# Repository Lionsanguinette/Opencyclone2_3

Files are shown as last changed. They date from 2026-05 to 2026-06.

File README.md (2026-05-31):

# Opencyclone2_3
This repository contains the complete documentation and production files for Opencyclone_2.3, an open-source vacuum cleaner developed by Lion Sanguinette and originally initiated together with Jonathan Stein during their Industrial Design studies at Burg Giebichenstein University of Art and Design.

The folders include all files required to understand, reproduce, modify, and further develop the project. These comprise 3D-printable STL files, editable CAD data in STEP format, technical components, preparation files, assembly instructions, and part lists. The documentation is structured to support both individual makers and professional manufacturers.

Opencyclone_2.3 explores how an everyday industrial product can be redesigned as an open, repairable, and adaptable system. By making all relevant design and production information publicly accessible, the project encourages local manufacturing, repair, and collaborative development while demonstrating that open-source hardware can achieve the functionality and quality expected from contemporary consumer products.

The repository is intended not only as a source of manufacturing data, but also as a resource for learning, experimentation, and further contributions to the project.

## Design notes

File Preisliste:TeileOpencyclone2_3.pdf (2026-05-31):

## OPENCYCLONE_2.0 Preisliste

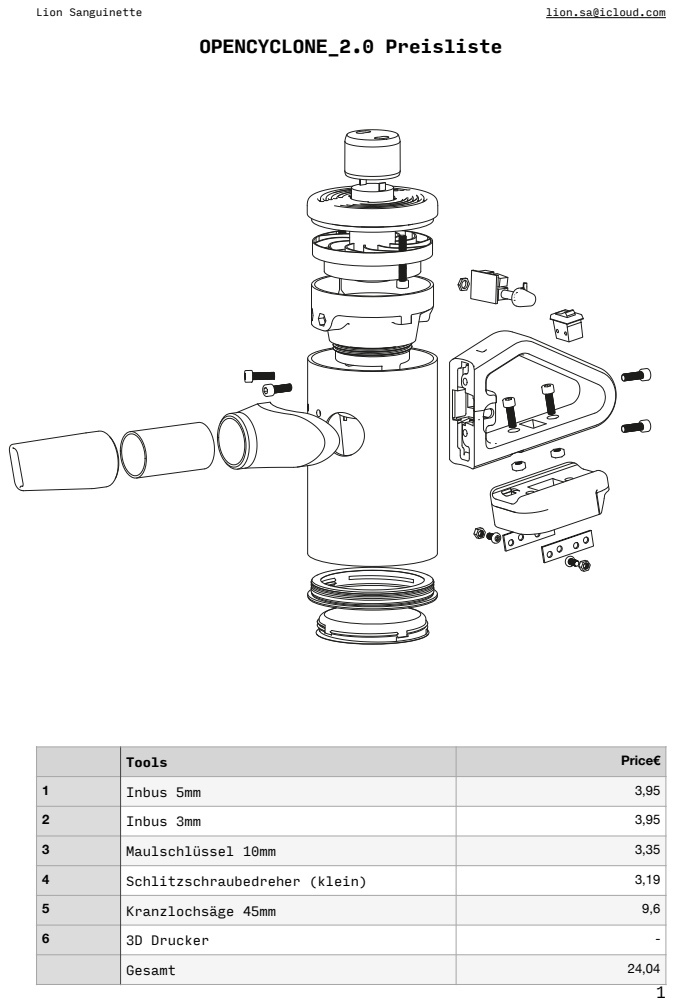
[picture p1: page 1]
Lion Sanguinette; lion.sa@icloud.com

Tools | Price€

1 | Inbus 5mm | 3,95
2 | Inbus 3mm | 3,95
3 | Maulschlüssel 10mm | 3,35
4 | Schlitzschraubedreher (klein) | 3,19
5 | Kranzlochsäge 45mm | 9,6
6 | 3D Drucker | -

Gesamt | 24,04

| Parts | Order € | Maß/ Gewicht/ Anzahl | Preis pro Staubi €
| Elektronik
1 | Kabel (Litze) 2,5 mm^2 | 5,51 | 2x 24cm/ 10cm/ 12cm/ 7cm | 0,67
2 Ringkabelschuhe M5 | 0,5-1,5mm^2 | 1,06 | 2 | 1,06
3 Flachsteckhülsen | 4,75mm/ 0,5 - 1,5mm^2 | 0,14 | 2 | 0,14
4 | Drehzahlregler | 6,59 | 1 | 3,30
5 | Makita Motor | 18,86 | 1 | 18,86
6 | Kippschalter | 4,69 | 1 | 4,69
| | 36,85 | | 28,72
| Zubehör
7 | AEG Staubsaugerfilter | 9,99 | 1 | 2,50
8 PVC Rohr HT Rohr DN 110 | 1000mm | 5,75 | 1 | 1,15
9 | PVC Rohr HT Rohr DN 40 | 1,75 | 1 | 0,15
10 | Filament | 19,99 | 370 gramm | 7,4
| | 37,48 | | 11,2
| Schrauben
11 M6 20mm DIN 912 | Zylinderkopfschraube | 4,7 | 6 | 2,79
12 M6 40mm DIN 912 | Zylinderkopfschraube | 7,7 | 2 | 0,16
13 M6 DIN934 | Sechskantmutter (Standard) | 3,2 | 6 | 0,19
14 50x14x1,5mm | Flachverbinder | 0,7 | 2 | 0,7
15 M5 10mm ISO 7380-1 | Halbrundkopfschrauben | 8,15 | 2 | 0,17
16 M5 DIN934 | Sechskantmutter (Standard) | 2,85 | 2 | 0,06
| | 27,3 | | 4,07
| Gesamt (ohne Werkzeug und ohne Akku/ Akku Ladegerät) | 101,63 | | 43,99

Elektronik

### 1. Kabel 1mm^2 14/24/34mm

https://www.amazon.de/FLRY-Fahrzeugleitung-Kabel-Litze-Stromkabel/dp/B084HJWB2L/ref=sr_1_2?
dib=eyJ2IjoiMSJ9.qZGsqN8sAAxVa8o9y76S6dpiOHtgGXHqAOTrmUuY-LMnbB7nG-Oez9AaiAFvBpkFwvrB_rPc78LBDjtlzVq9vFilTANlSffE6aziZaihkvtN4EEs6zam1IwDDk31IfwVawDfjtOBFEcokXE_r4PCuKUOH0ud_jtLoobG23XEh2DmEu kJ3Z9aXWFDzKOfBv3FD9QLBLBDuhHGmRxZ1EyPJz2Zhsra27_PiZioHDBMR0.KwxVImxPzgiQeh DF1qKaO4M2_oIU0M-6CLbmFAVlNJU&dib_tag=se&keywords=5m%2BFLRY%2BFahrzeugleitu ng%2BBlau%2Brund%2BKabel%2BLitze%2BKFZ%2BStromkabel&qid=1747909130&sr=8-2&t h=1 (https://www.amazon.de/FLRY-Fahrzeugleitung-Kabel-Litze-Stromkabel/dp/B084HJWB2L)

### 2. Ringkabelschuhe 2x

https://www.reichelt.de/de/de/shop/produkt/ringkabelschuh_mit_schrumpfschlauch_-_0_5_1_5_mm_m5_rot-189411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 (https://www.reichelt.de/de/de/shop/produkt/ringkabelschuh_mit_schrumpfschlauch_-_0_5_1_5_mm_m5_rot-189411) https://www.reichelt.de/de/de/shop/produkt/ringkabelschuhe_m4_0_5_-_1_5_mm_100_st_-332538?
PROVID=2789&msclkid=5149cdad45df1600c886aa87761485d8&utm_campaign=%28DE%3A+ All+Products%29+Marge+11+-&utm_medium=cpc&utm_source=bing (https://www.reichelt.de/de/de/shop/produkt/ringkabelschuhe_m4_0_5_-_1_5_mm_100_st_-332538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)

### 3. Flachsteckhülse 2x

https://www.reichelt.de/de/de/shop/produkt/flachsteckerhuelse_breite_4_75mm_rot-7912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 dal (https://www.reichelt.de/de/de/shop/produkt/flachsteckerhuelse_breite_4_75mm_rot-7912?PROVID=2788&gad_source=1)

### 4. Drehzahlregler Modul Mini DC Motor PWM

https://www.amazon.de/dp/B07XTFLCWN?ref=ppx_yo2ov_dt_b_fed_asin_title

### 5. Makita Motor DCL180

https://www.agrodirect.at/index.php/shop/maschinen-e-ger%C3%A4te/makita/maersatzteile/ma-saugen/makita-motor-125867-6-komplett-dcl180-detail (https://www.agrodirect.at/index.php/shop/maschinen-e-ger%C3%A4te/makita/ma-ersatzteile/ma-saugen/makita-motor-125867-6-komplett-dcl180-detail) https://www.kaufland.de/product/455972037/https://de.aliexpress.com/i/32854352680.html

### 6. Kippschalter mit Schraubanschluss

https://www.amazon.de/Wippschalter-mit-Schraubanschluss-schwarz-230V/dp/B06Y1RDBZ7 (https://www.amazon.de/Wippschalter-mit-Schraubanschluss-schwarz-230V/dp/B06Y1RDBZ7)

Zubehör

### 7. AEG Staubsaugerfilter

https://www.amazon.de/1ELEMENT-Filter-Staubsauger-ersetzt-AEF150/dp/B0C3GVRV8Y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 vgbm0LO0e2o0SGsNT7pcvw5ZoE8.B-a9gfzt7qVF53PgpgNOyo_dWYH6ep5OfjL1Ou2fA4&dib_tag=se&keywords=aeg%2Bstaubsaugerfilter&qid= 1741626021&rdc=1&sr=8-5-spons&sp_csd=d2lkZ2V0TmFtZT1zcF9hdGY&th=1 (https://www.amazon.de/1ELEMENT-Filter-Staubsauger-ersetzt-AEF150/dp/B0C3GVRV8Y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)

### 8. PVC Rohr DN110

https://www.hornbach.de/p/ht-rohr-dn-110-2000-mm/266955/

### 9. PVC Rohr DN40

https://www.hornbach.de/p/ht-rohr-dn-40-1000-mm/209789/
10a. Flida PLA Filament 150 Gramm (1kg/ 20€) https://www.3djake.de/polymaker/polyterra-pla-lavender-purple 10b. Orange PLA Filament 220 Gramm (1kg/ 20€) https://www.3djake.de/polymaker/polyterra-pla-sunrise-orange
Schrauben/ Metallteile
11. 6x M6 20mm DIN 912 Zylinderkopfschraube https://www.hornbach.de/p/zylinderschraube-m-innensechskant-inbus-din-912-vollgewinde-m6x20-mm-8-8-galv-verzinkt-10-stueck/10715732/ (https://www.hornbach.de/p/zylinderschraube-m-innensechskant-inbus-din-912-vollgewinde-m6x20-mm-8-8-galv-verzinkt-10-stueck/10715732/)
12. 2x M6 40mm DIN 912 Zylinderkopfschraube https://www.hornbach.de/p/zylinderschraube-m-innensechskant-din-912-m6x40-mm-galv-verzinkt-100-stueck/6834884/ (https://www.hornbach.de/p/zylinderschraube-m-innensechskant-din-912-m6x40-mm-galv-verzinkt-100-stueck/6834884/)
13. 6x M6 DIN934 Sechskantmutter (Standard) https://www.hornbach.de/p/sechskantmutter-din-934-m6-galv-verzinkt-100-stueck/3830636/ (https://www.hornbach.de/p/sechskantmutter-din-934-m6-galv-verzinkt-100-stueck/3830636/)
14. 2x 50x14x1,5mm Flachverbinder (z.B. Kaiserthal)
(Wichtig! Stärke max. 1,5mm) https://www.hornbach.de/p/flachverbinder-50x14-mm-sendzimirverzinkt-1-stueck/10610114/?
marketNo=636&wt_mc=de.paid.sea.google.alwayson_assortment.eis.pla.868482955 .108350938553.&wt_cc1=868482955&wt_cc2=108350938553&wt_cc3=457417566875&wt_ cc4=&wt_cc6=10610114&wt_cc7=636&gad_source=1&gclid=Cj0KCQjwm7q-BhDRARIsACD6-fVGs5SyTGvImMa84lOyyVeKYqLTmJRbQQHJfeNpNMpOgVqrX7YBrIaAhEKEALw_wcB (https://www.hornbach.de/p/flachverbinder-50x14-mm-sendzimirverzinkt-1-stueck/10610114/?marketNo=636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)
15. 2x M5 10mm ISO 7380-1 Halbrundkopfschrauben https://www.hornbach.de/p/halbrundkopfschraube-iso-7380-1-m5x10-mmedelstahl-a2-100-stueck/6834898/ (https://www.hornbach.de/p/halbrundkopfschraube-iso-7380-1-m5x10-mm-edelstahl-a2-100-stueck/6834898/)
16. 2x M5 DIN934 Sechskantmutter (Standard) https://www.hornbach.de/p/sechskantmutter-din-934-m5-galv-verzinkt-100-stueck/3830634/ (https://www.hornbach.de/p/sechskantmutter-din-934-m5-galv-verzinkt-100-stueck/3830634/)
(Alles im Baumarkt erhältlich)

Werkzeuge
1. Inbus 5mm https://www.hornbach.de/p/inbus-71529-winkelschraubendreherextra-lang-5mm-mit-kugelkopf-made-in-germany/10327232/ (https://www.hornbach.de/p/inbus-71529-winkelschraubendreher-extra-lang-5mm-mit-kugelkopf-made-in-germany/10327232/)
2. Inbus 3mm https://www.hornbach.de/p/inbus-71574-winkelschraubendreherextra-lang-10mm-mit-kugelkopf-made-in-germany/10327256/ (https://www.hornbach.de/p/inbus-71574-winkelschraubendreher-extra-lang-10mm-mit-kugelkopf-made-in-germany/10327256/)
3. Maulschlüssel 10mm https://www.hornbach.de/p/doppelmaulschluessel-wgb-10-x-11-mm/8415949/ (https://www.hornbach.de/p/doppelmaulschluessel-wgb-10-x-11-mm/8415949/)
4. Schlitzschraubendreher (klein) https://www.hornbach.de/p/makitaschraubendreher-sl6-5-mit-schlagkappe-e-04949/12363976/ (https://www.hornbach.de/p/makita-schraubendreher-sl6-5-mit-schlagkappe-e-04949/12363976/)
5. Lochsäge Wolfcraft 45mm https://www.hornbach.de/p/standardmehrkranzlochsaege-set-wolfcraft-metall-o-25-62-mm-7-tlg/931522/ (https://www.hornbach.de/p/standard-mehrkranzlochsaege-set-wolfcraft-metall-o-25-62-mm-7-tlg/931522/)

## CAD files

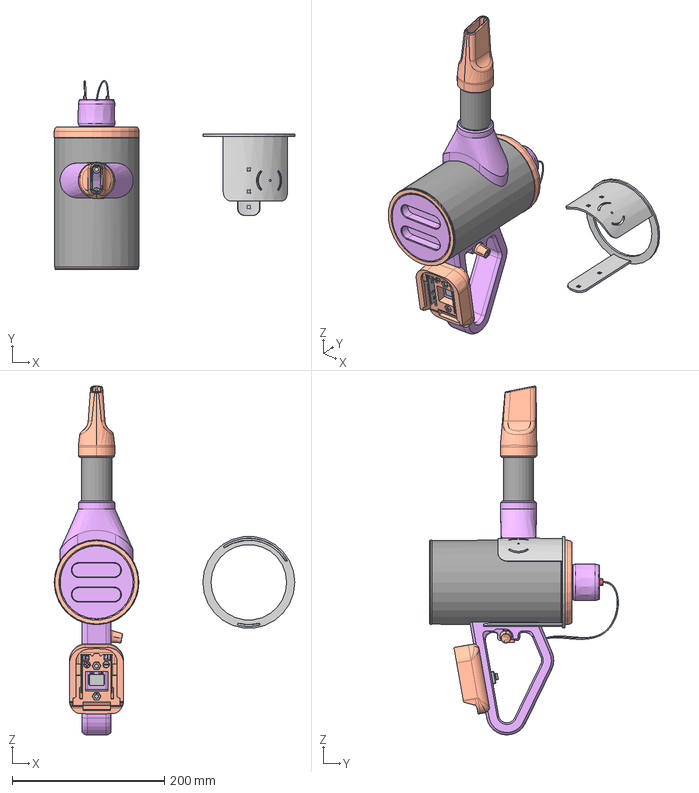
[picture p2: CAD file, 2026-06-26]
CompleteFile/20260626_Opencyclone2_3.step
316.2 x 248.2 x 458.5 mm
20260626_Deckel
20260626_Aufsatz
20260626_Verbinder
20260626_Akkuadapter
20260626_Motorabdeckung
20260626_Luftfilter(demo)
20260626_Griff
20260626_Filterhalter
20260626_Boden_Außengewinde
20260626_Boden_Innengewinde
20260626_Filterhalter_2
20260626_Knopf
Schrauben/Metall
PVC
Elektronik
Bohr_Schablone

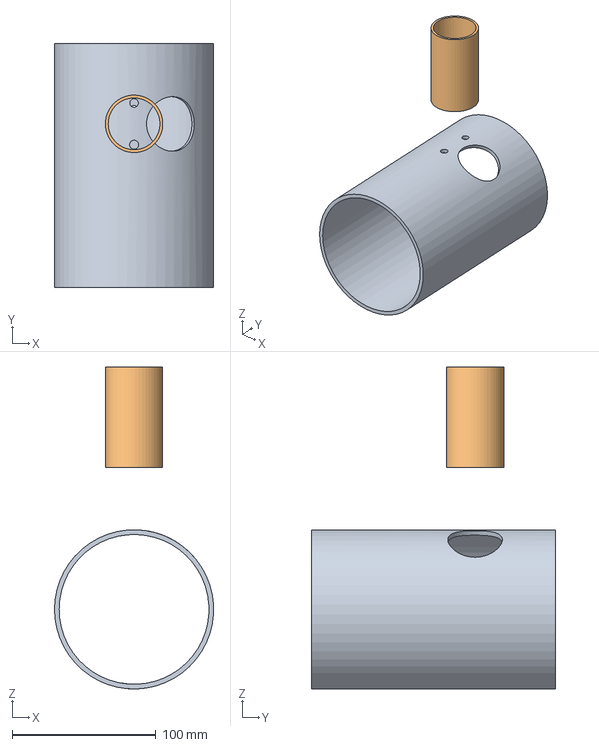
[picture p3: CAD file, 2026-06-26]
STEPs/20250626_PVCpipes.step
110.8 x 170.0 x 224.2 mm

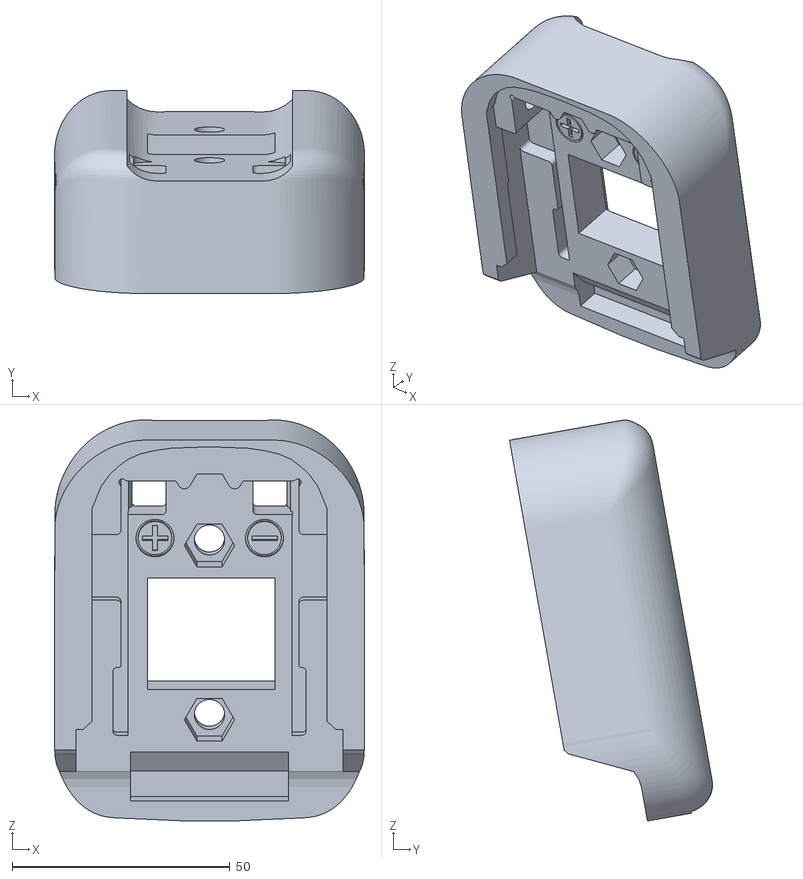
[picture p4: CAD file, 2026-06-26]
STLs(lowPoly)/20260626_Akkuadapter.stl
71.3 x 46.6 x 92.1

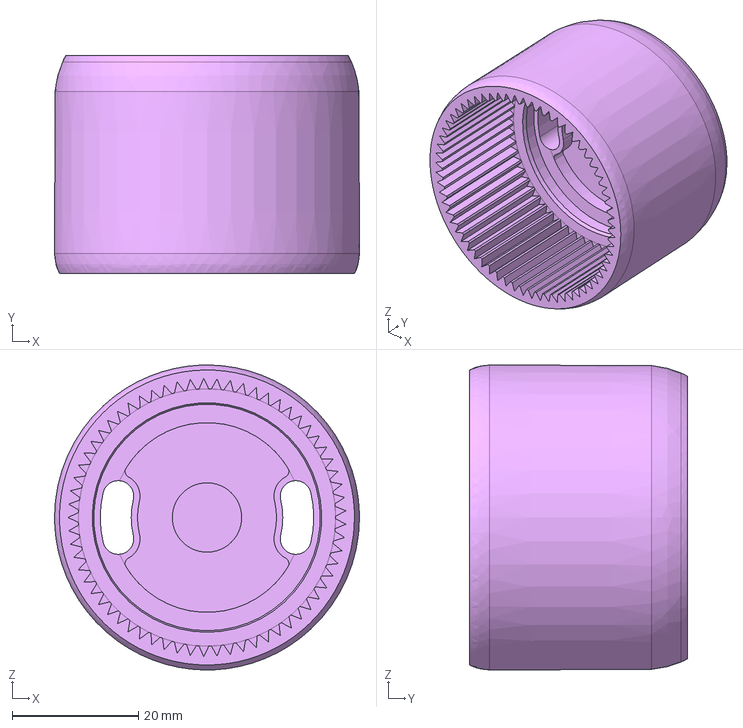
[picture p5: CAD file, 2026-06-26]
STEPs/20250626_Motorabdeckung.step
48.4 x 34.6 x 48.3 mm

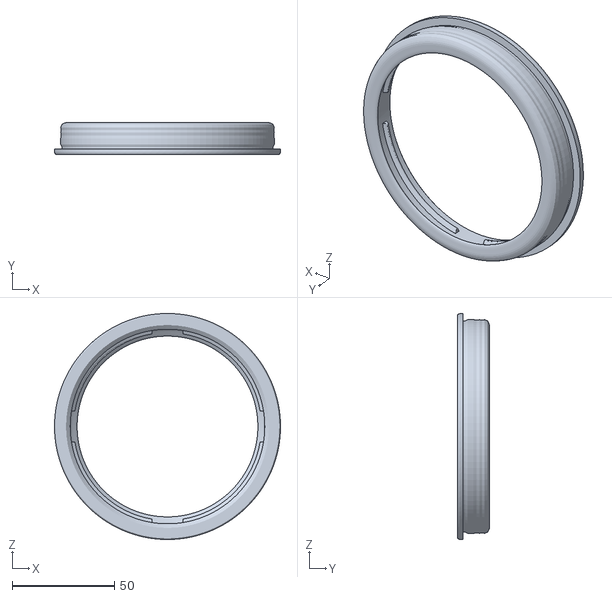
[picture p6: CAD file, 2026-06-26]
STLs(lowPoly)/20260626_Boden_Außengewinde.stl
110.8 x 15.9 x 110.8

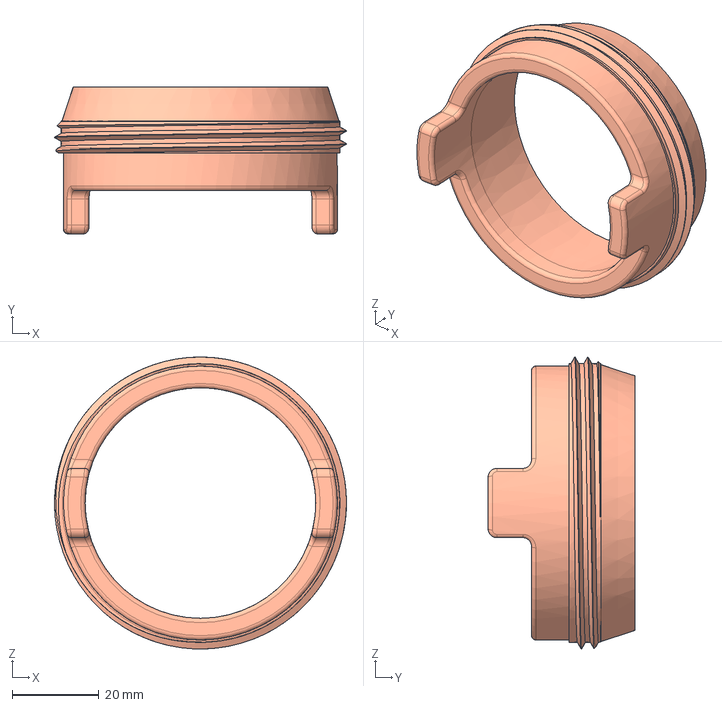
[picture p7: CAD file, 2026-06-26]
STEPs/20250626_Filterhalter_2.step
67.4 x 33.9 x 67.4 mm

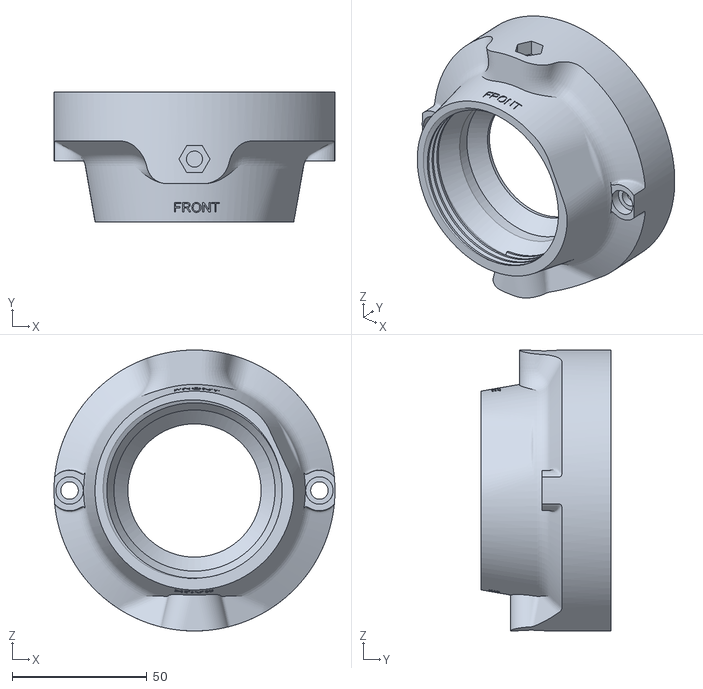
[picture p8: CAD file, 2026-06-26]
STLs(lowPoly)/20260626_Filterhalter.stl
104.2 x 48.1 x 104.2

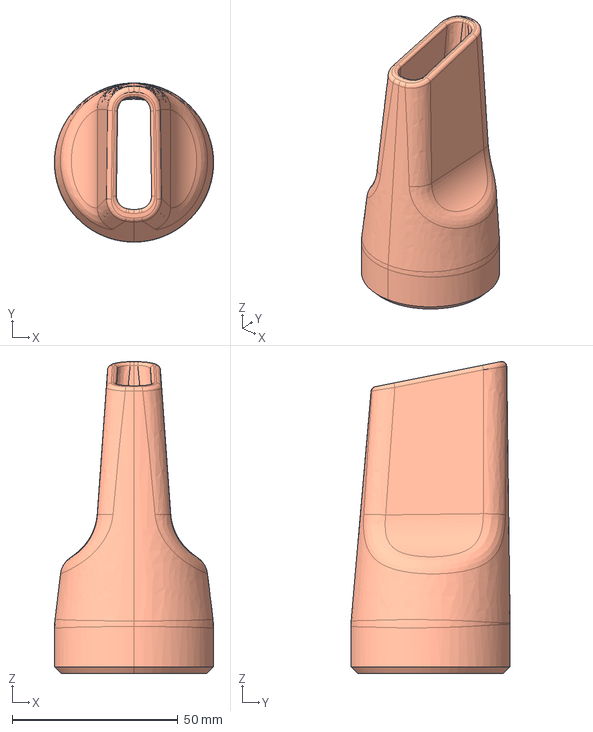
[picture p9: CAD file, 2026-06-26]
STEPs/20250626_Aufsatz.step
48.0 x 48.0 x 94.0 mm

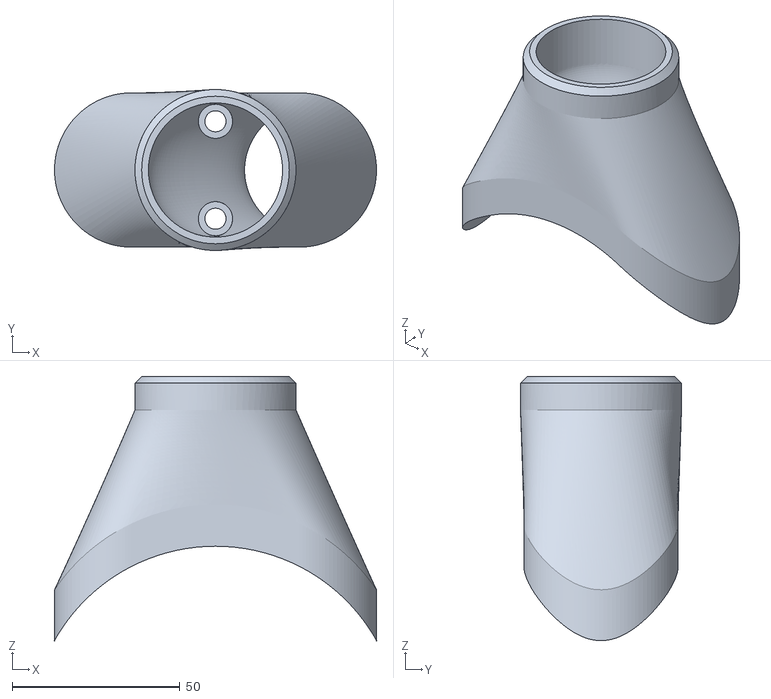
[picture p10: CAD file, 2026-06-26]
STLs(lowPoly)/20260626_Verbinder.stl
96.0 x 48.0 x 78.8

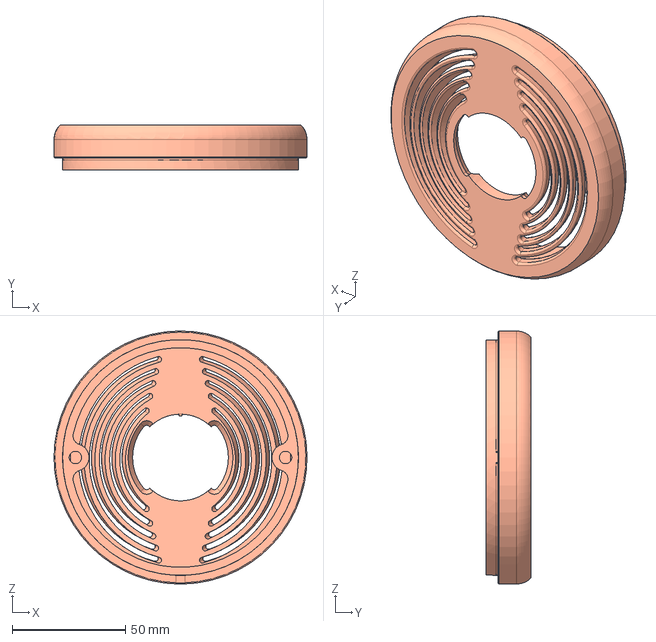
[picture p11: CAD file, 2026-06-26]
STEPs/20250626_Deckel.step
111.5 x 19.7 x 111.5 mm

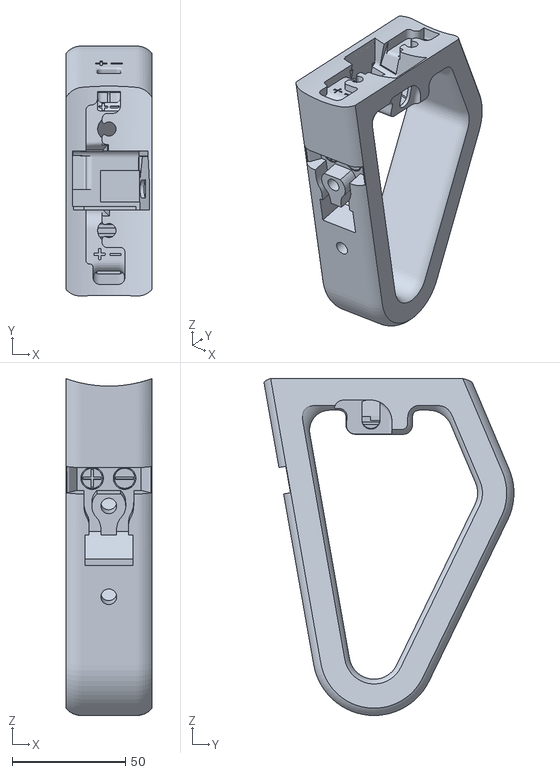
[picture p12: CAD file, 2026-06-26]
STLs(lowPoly)/20260626_Griff.stl
38.0 x 110.1 x 148.5

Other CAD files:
STLs(lowPoly)/20260626_Filterhalter_2.stl
STEPs/20250626_Filterhalter.step
STLs(lowPoly)/20260626_Deckel.stl
STEPs/20250626_Akkuadapter.step
STEPs/20250626_Verbinder.step
STLs(lowPoly)/20260626_Motorabdeckung.stl
STEPs/20250626_Boden_Außengewinde.step
CompleteFile/20260626_Opencyclone2_3(Derived2).f3d
STEPs/20250626_Boden_Innengewinde.step
STEPs/20250626_Griff.step
STEPs/20250626_Knopf.step
STLs(lowPoly)/20260626_Aufsatz.stl
STLs(lowPoly)/20260626_Boden_Innengewinde.stl
STLs(lowPoly)/20260626_Knopf.stl

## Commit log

2026-05-31 Create STL
2026-06-18 Rename STL to STL Repo links.txt
